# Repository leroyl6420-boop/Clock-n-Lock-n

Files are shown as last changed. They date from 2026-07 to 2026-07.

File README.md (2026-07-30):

# Clock'n Lock'n
A punch clock that you can use to keep track of the time you work and keep you motivated!

I worked on this project to get myself to do more work! I guess that you gotta work to get work done ;)

Pros:

- Gives you a physical item as proof of your work!
- Motivates you to get your things done!
- Fun to make!

Cons:

- I KEEP ON WORKING IN TEN HOUR CHUNKS AND I CANT STOP PLEASE HELP ME

I hope that my repo helps you make your very own Clock'n Lock'n! Have fun! (P.S. I used OLEDs which is why the screen in the picture below is glitched out)

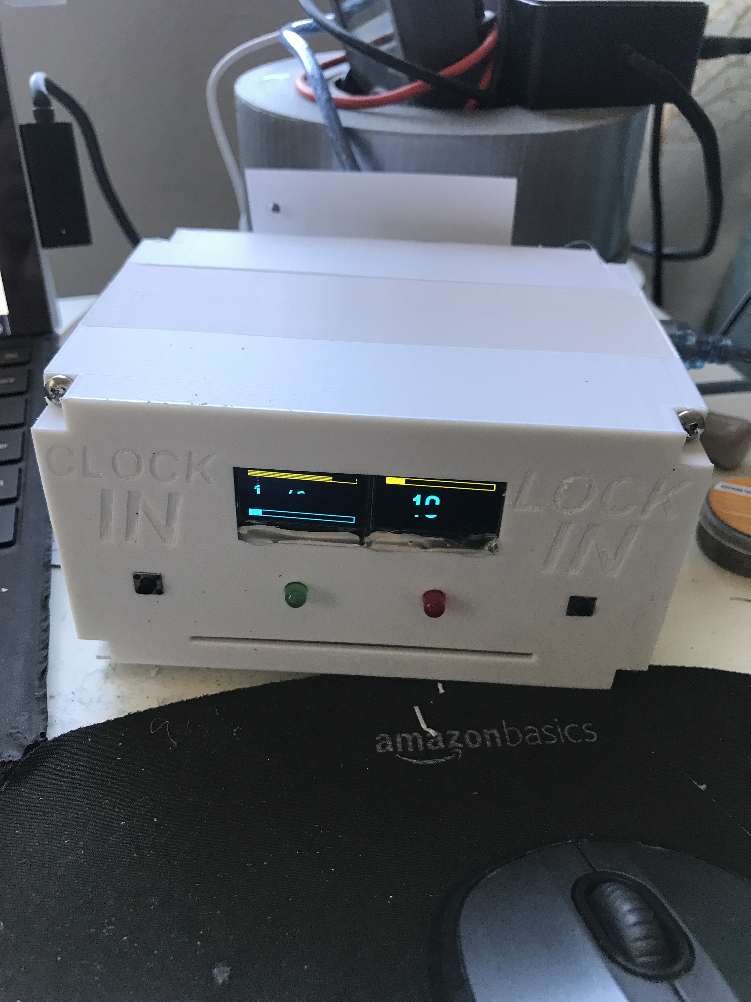
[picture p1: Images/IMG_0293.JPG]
An image of the finished Clock'n Lock'n!


The following are instructions on how to build the Clock'n Lock'n for yourself:

# PARTS TO PRINT

Print all of the parts in the Parts to Print file!

- Case
- Back Case
- Face
- Spiral Gear
- Servo Gear
- Pin

The total cost will vary based on what type of filament you use, and how many times you mess up the prints :P

# PHYSICAL COMPONENTS

Here is everything you need to buy off Amazon, AliExpress, and Temu: 

- 2 5mm LEDs: $0.04
- 2 5mm Push Buttons: $0.50
- 2 128x64 OLEDS: $5.00
- 1 28BYJ-48 Stepper Motor plus ULN2003 Motor Driver: $5.00
- 1 SG90 Servo Motor: $1.20
- 1 Mini Breadboard: $1.25
- 1 Arduino Uno R3: $8.00
- 4 220 ohm Resistors: $0.20
- 2 1K ohm Resistors: $0.10
- 2 Photoresistors: $1
- 10 #6-32 1in Screws: $1.57
- Jumper Wires: Will Vary

In total, everything will run you around $23.86, definitely less than $30 (: 

# ASSEMBLY INSTRUCTIONS

Hot-glue the Arduino and the ULN2003 onto the back of the case. Hot glue the Servo motor onto its mount. Screw the 28BYJ-48 Stepper Motor onto its mount using two #6-32 screws. Attach the Servo Gear onto the Servo motor. Attach the Spiral Gear onto the Stepper motor. Put the pin in its slot with a pen's spring pushing it up. Hot glue all the LEDs, buttons, OLEDs, and photoresistors into place. Connect one leg of every LED and photoresistor to GND. Every LED's other leg goes to a 220 ohm resistor, then their digital pin (see in code). The photoresistors go to a 10k ohm resistor, then their analog pin (see code). Wire everything else as stated in code. Congrats, you have just built your very own Clock'n Lock'n!

# AI USE
AI was used to debug the code.

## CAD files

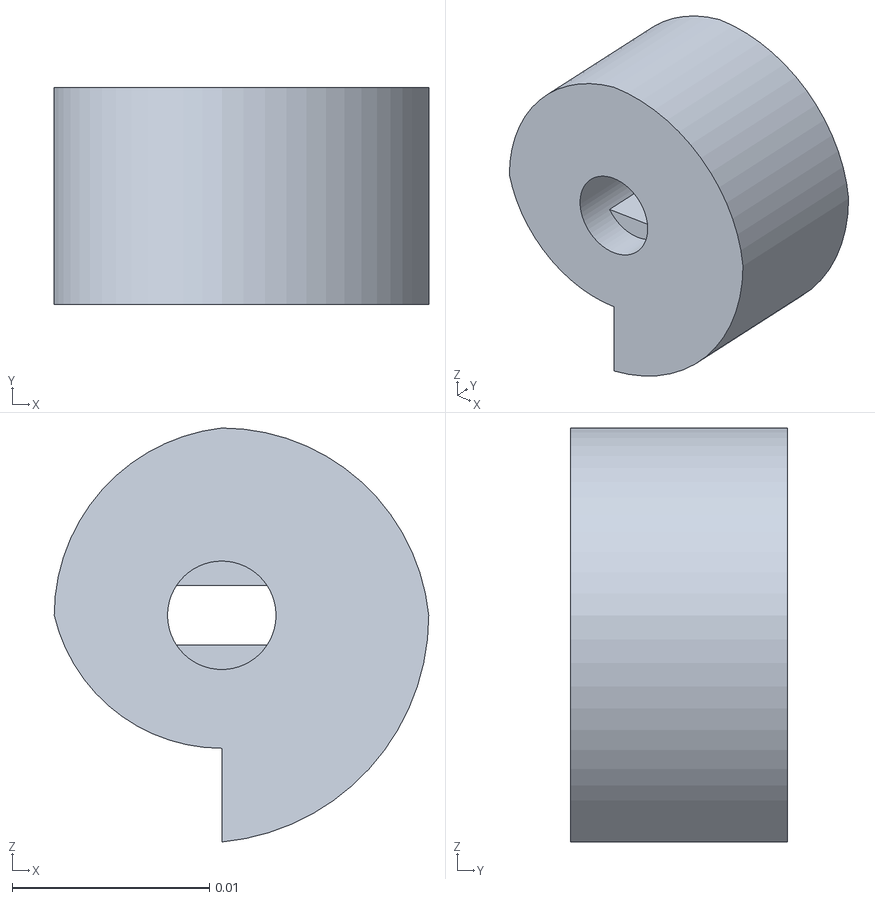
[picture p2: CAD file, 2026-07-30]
Parts to Print/Spiral Gear.stl
0.019 x 0.011 x 0.021

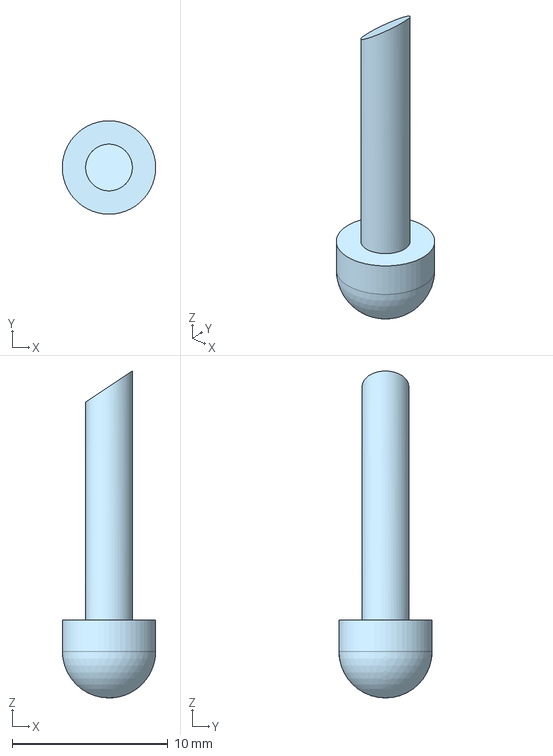
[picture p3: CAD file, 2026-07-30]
STEP Files/Pin.step
6.00 x 6.00 x 21.0 mm

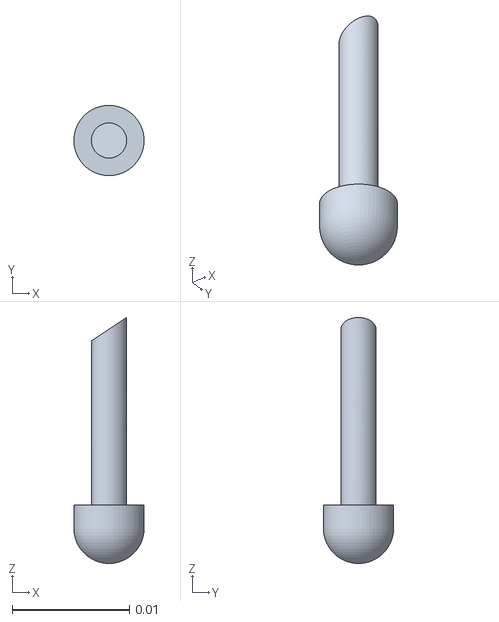
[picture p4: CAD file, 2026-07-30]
Parts to Print/Pin.stl
0.006 x 0.00599 x 0.021

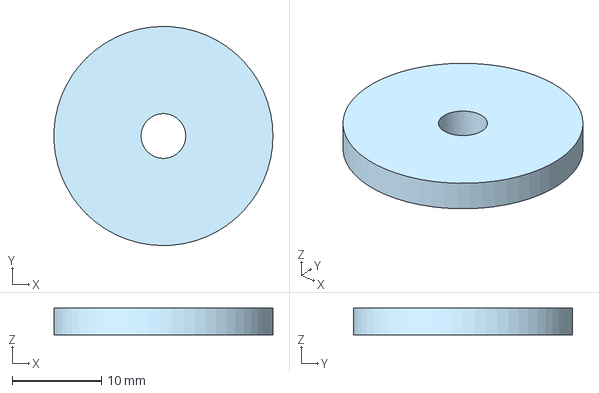
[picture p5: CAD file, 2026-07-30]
STEP Files/Servo Gear.step
24.5 x 24.5 x 3.00 mm

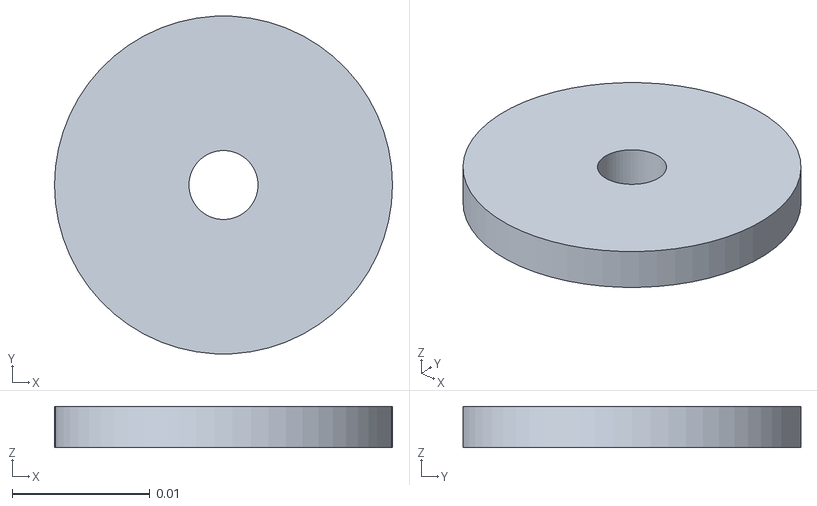
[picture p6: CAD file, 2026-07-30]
Parts to Print/Servo Gear.stl
0.0245 x 0.0245 x 0.003

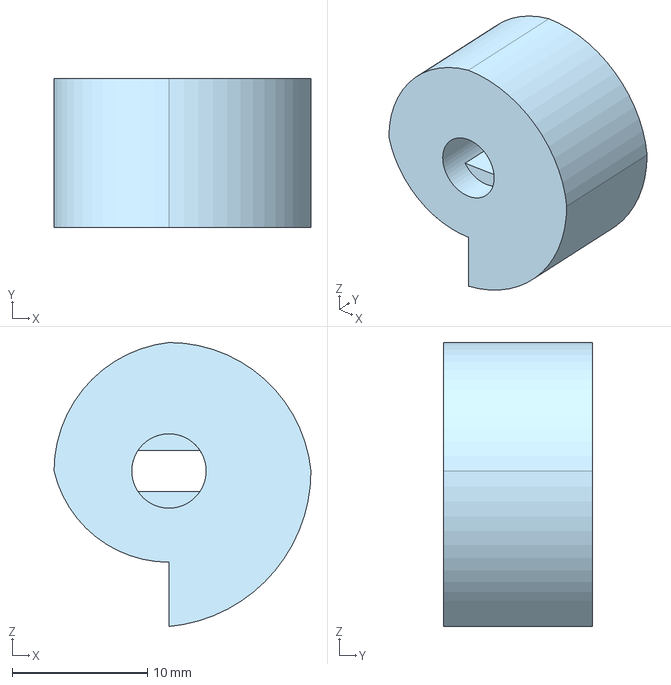
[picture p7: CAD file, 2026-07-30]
STEP Files/Spiral Gear.step
19.0 x 11.0 x 21.0 mm

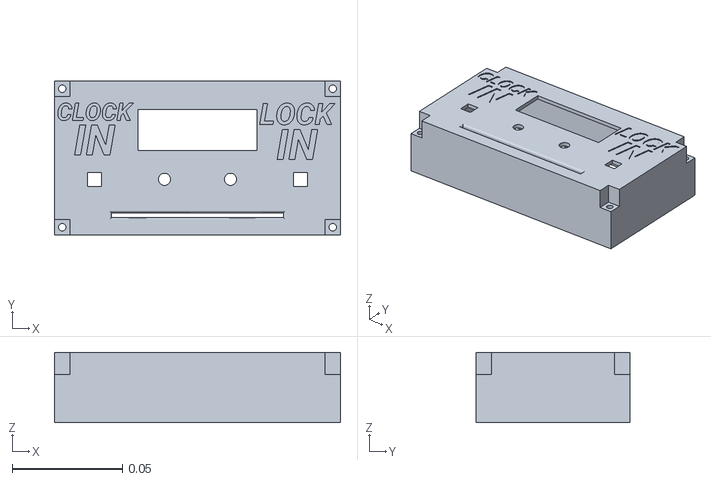
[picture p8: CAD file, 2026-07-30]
Parts to Print/Face.stl
0.13 x 0.07 x 0.032

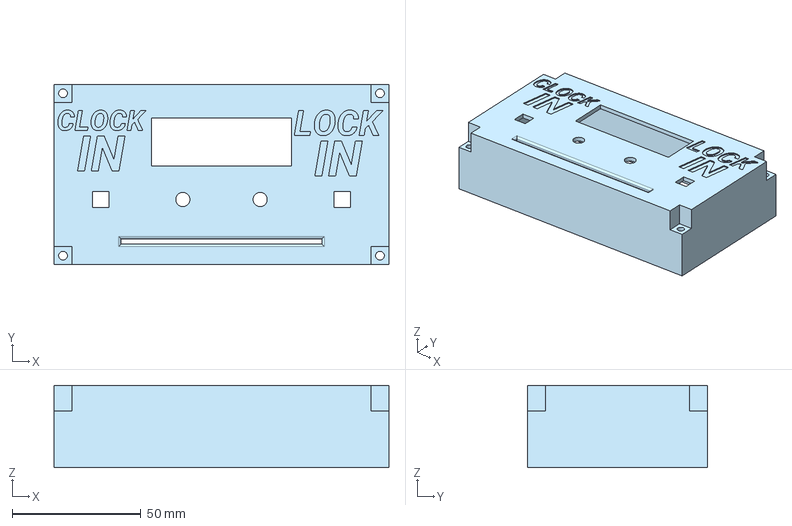
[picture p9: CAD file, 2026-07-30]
STEP Files/Face.step
130.0 x 70.0 x 32.0 mm

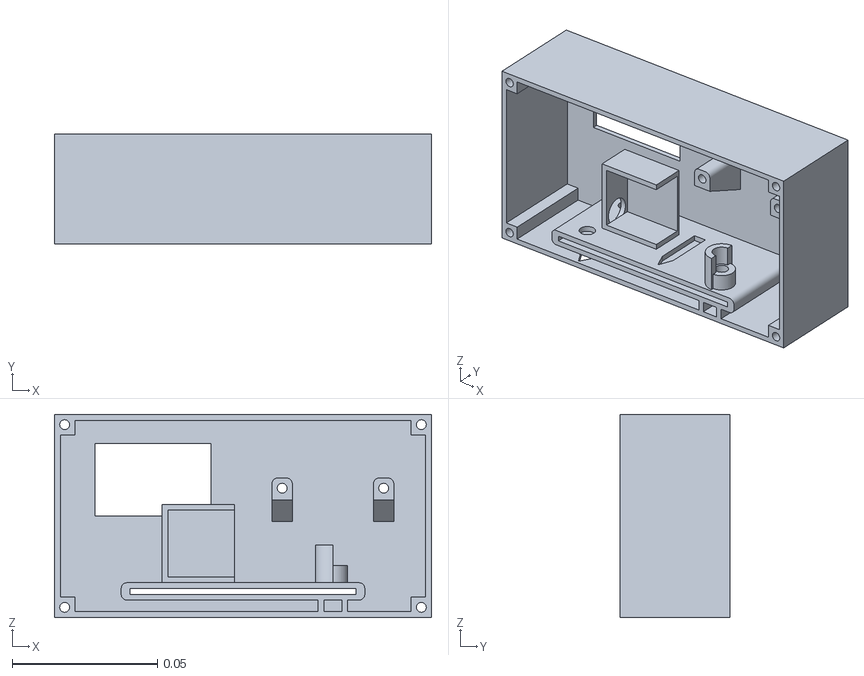
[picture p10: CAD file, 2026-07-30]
Parts to Print/Case.stl
0.13 x 0.038 x 0.07

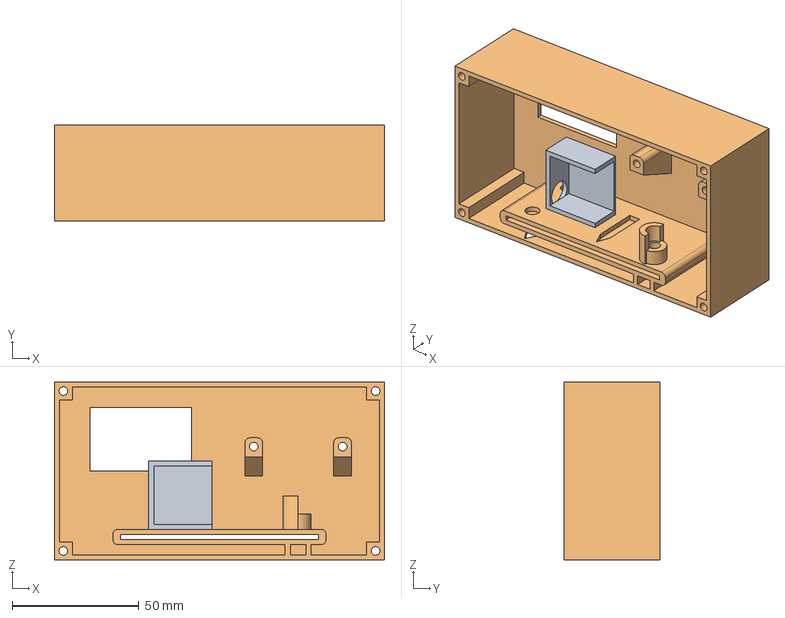
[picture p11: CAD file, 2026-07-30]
STEP Files/Case.step
130.0 x 38.0 x 70.0 mm

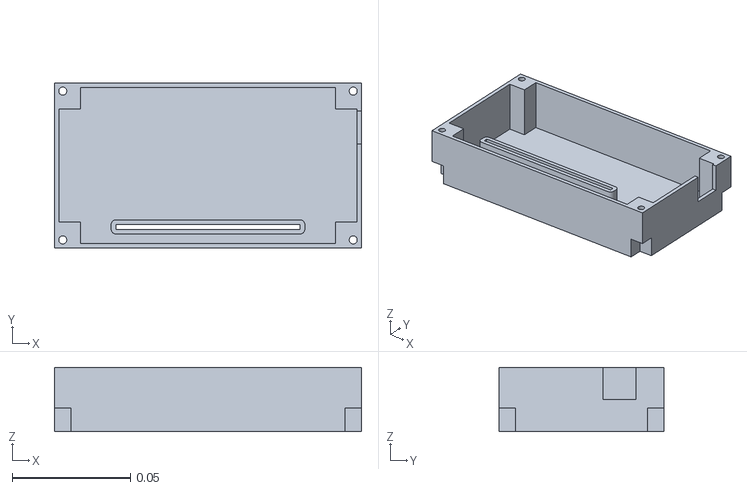
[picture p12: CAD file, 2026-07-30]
Parts to Print/Back Case.stl
0.13 x 0.07 x 0.0272

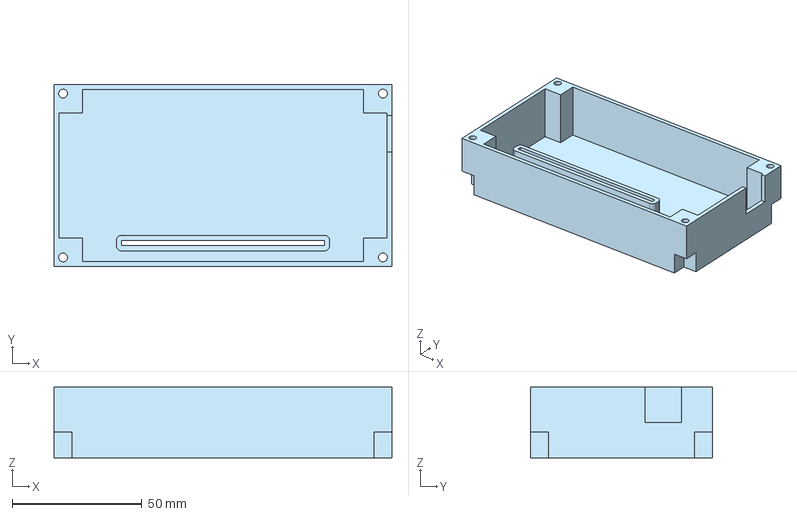
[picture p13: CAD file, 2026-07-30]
STEP Files/Back Case.step
130.0 x 70.0 x 27.2 mm

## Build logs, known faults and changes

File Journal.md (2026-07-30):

# Lock'n Clock'n

Hi! Welcome to my journal for my Lock'n Clock'n project!

# Devlog 1
1h 5m 4s Logged

I started the Lock'n Clock'n today! I cadded the case, the face, and the punch card. I think I'll just use index cards for those. I still don't know how I'll punch the cards, but I'm sure that I'll figure it out. In the meantime, I also added some 3D models of the parts I'll be using, and I CADed screw holes and text. I'm excited to keep going!

A picture of the initial Lock'n Clock'n CAD!

# Devlog 2
1h 21min Logged

I CADed the system that will detect the position of the punch card in the Clock'n Lock'n. There will be an LED and a photoresistor, and the LED will constantly shine on the photoresistor. However, when the punch card is pushed through, the photoresistor will sense the light level drop. When a hole on the side of the punch card comes up, the light level will return to normal, and the Clock'n Lock'n will know the position of the punch card. I also started CADing the movement system. I plan to use a 28BYJ-48 Stepper Motor for percise control. I will need a second LED-photoresistor system to trigger it, or I will need to move the initial one up. We'll see which is more convenient for spacing. Yes, space management has been a real issue in this project. I wanted it to take up little space, so you could easily put it on your desk, but it seems I will have to make some comprimises. 

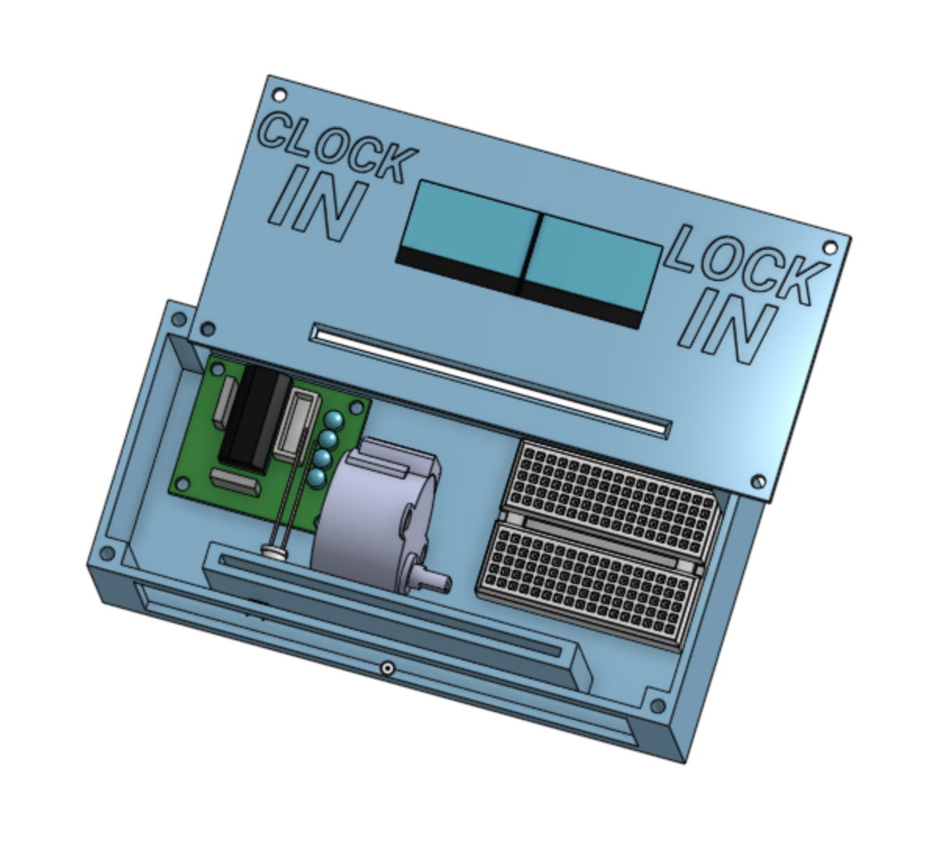
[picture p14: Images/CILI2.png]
An image of the Clock'n Lock'n with its partially completed position-detecting and punch-card-moving systems


# Devlog 3
1h Logged

I CADed the Stepper mount and the wheel that will push the paper through the slot. Not a lot to say, just took a long time. 

Exactly what it sounds like

# Devlog 4
1h 41min 28sec Logged

I coded and built the first prototype of the Clock'n Lock'n! I just had one position detection module and the movement module for now. The code was pretty simple, just a continuously spinning motor and a reading photoresistor. I think that I need a two-point axle for the movement module, as it was too flimsy and wouldn't hold in place. The position detection system worked well, as it gave a 32-unit difference between the punches. I need to make the case larger to fit an internal puncher and the movement module's second axle point. In the meantime, the test worked well!

An image of the first test of the Clock'n Lock'n

# Devlog 5
1h 20min Logged

I got rid of the 28BYJ-48 Stepper motor and replaced it with a modified SG90 servo motor. I modified it by disconnecting the encoder and getting rid of the mechanical plastic catch, making it bacically a mini high-torque dc motor. I can control the speed, but I can't control the position anymore (due to the disconnected encoder). That's alright, as I can tell the position of the punch card anyway through the LED-photoresistor modules. Getting rid of the 28BYJ-48 in favor of the SG90 also has the benefit of saving space in the case, not only with the motor itself but also in the lack of a driver module. 

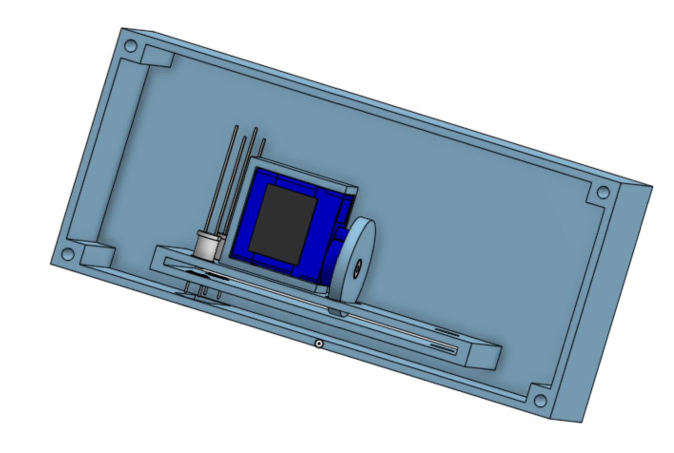
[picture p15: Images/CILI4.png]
A picture of the Clock'n Lock'n CAD, now with a servo motor instead of a stepper motor


# Devlog 6
1h 10m 50sec Logged

I coded the test code and part of the actual code. I had to spend time coding the logic on the positioning, and I also had to do some soldering on the back of one of my OLEDs to change its adress. Again, not a lot to say, just a lot of difficult work, troubleshooting, but getting there in the end (:

An image of the OLED which had its adress changed

# Devlog 7

42 min Logged

I built the first prototype of the Clock'n Lock'n! I couldn't figure out the stamping mechanism just yet, so I had to use a makeshift puncher consisting of a sharp chopstick, a bottle cap, and two pen springs. The new servo moving system works very well, though the position detection systems are not yet online. I need to make a hole puncher first. Overall, the tests that I set out to do with this prototype were all successes! I have new ideas on how to implement a stamp, like a solenoid (with a relay). 

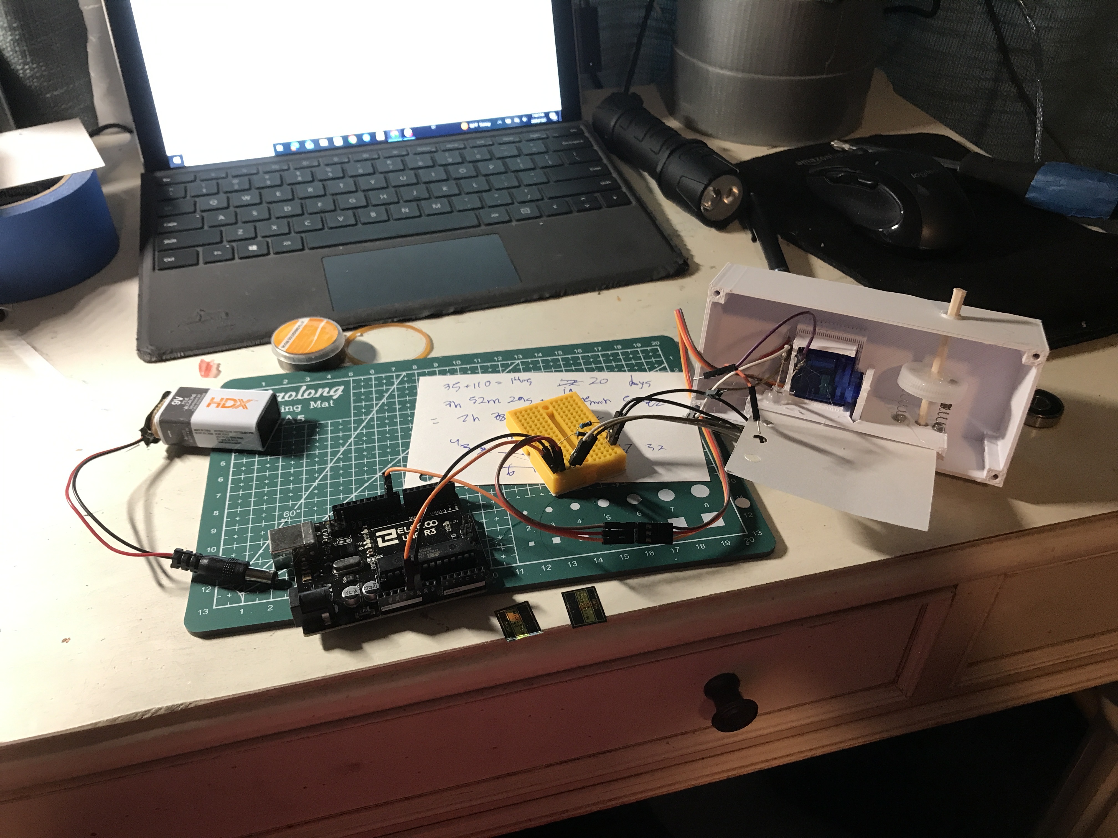
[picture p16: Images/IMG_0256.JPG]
A picture of the first prototype of the Clock'n Lock'n!


# Devlog 8
1h 32min Logged

I CADed a system to automatically punch holes in the paper! I did a lot of brainstorming, and I landed on a small pin with a rounded head that a cam would push onto. I modeled the bulk of it already, but I need to do some real-world testing before making any more decisions. I'm using a spring to hold the pin up, which is hard to model around. I also had to move the roof higher to fit the 28BYJ-48 stepper motor that I'm adding back, which sucks because I want to make this device as small as possible. Still, I'm telling myself that it was necessary, because the roof is now full of stuff and I can't put the buttons/LEDs that I was planning to add there. Instead, I'll have to add them onto the elongated face. 

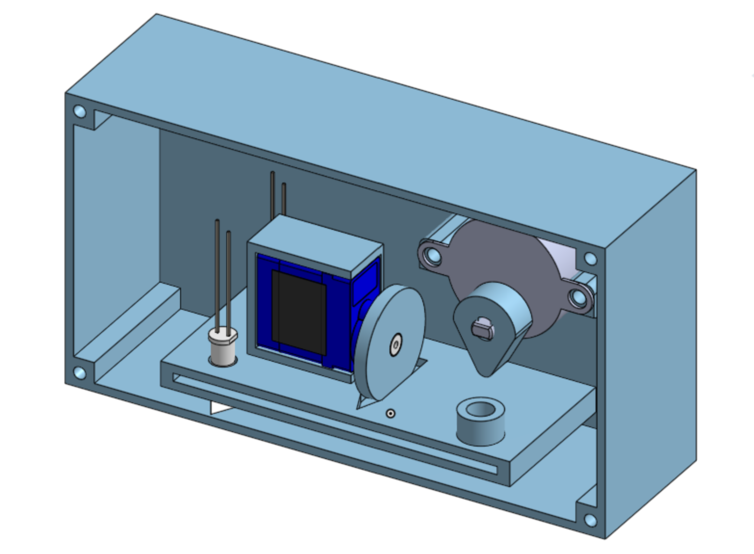
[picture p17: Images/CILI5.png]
An Image of the Clock'n Lock'n with the punch system modeled


# Devlog 9
1h Logged

I CADed a test case (without walls) to test the punch system while saving time and filament. I also CADed the puncher that I'll use to punch the 10 pre-punched holes into the index card. A lot of work, not a lot of words. 

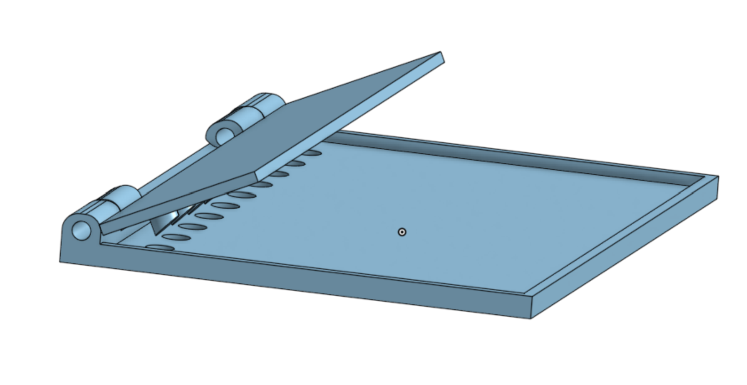
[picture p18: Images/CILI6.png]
An image of the index card puncher

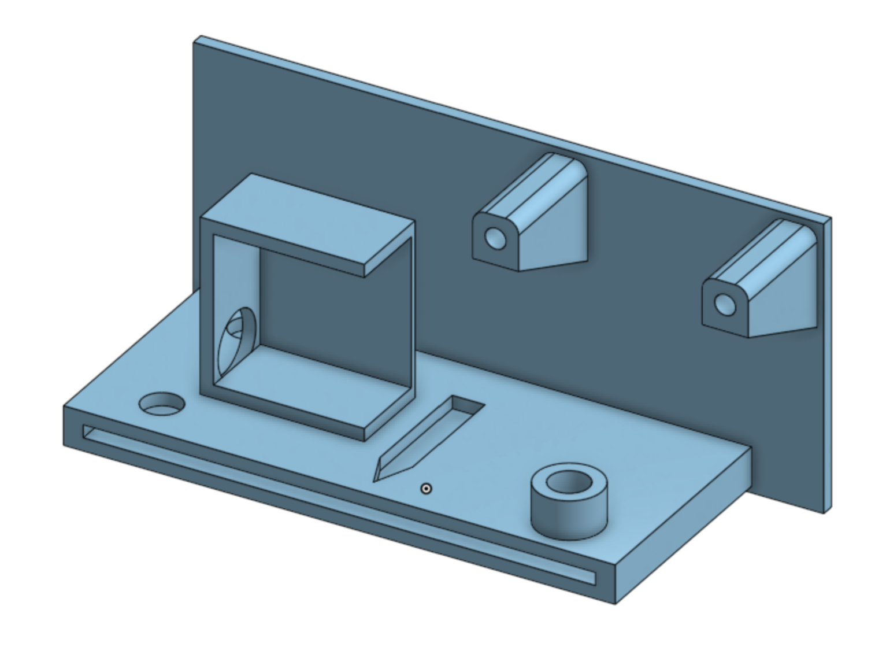
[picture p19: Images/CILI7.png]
An image of the test case


# Devlog 10
2h 17min Logged

Long working session! Lost track of time, I would have made seperate devlogs, but I'll just split this one into a software section and a hardware section. The software section goes first!

I coded the OLEDS into the Main file, and I coded the 28BYJ-48 Stepper Motor into both the Main file and the Test file. I coded some more logic into the Main file as well, like the paper positioning, the hole punching due to the hour count, etc. I was informed that each OLED screen will need 1024 bytes of RAM, but the Arduino Uno R3 only has 2000 available for the both of them. This means that I will need to work with a library that will lower the RAM usage in exchange for slower rendering times. I'm not worried about this, as the OLEDs' main function will be a clock and a progress bar. 

I printed out the testing case and attached the stepper motor with its cam gear. It seems that, while all dimensions are perfect in my model, the same can't be said in real life. Thankfully, I have prepared for this. I can fix the dimensioning problem by simply elongating the pin's length. However, I do need to fix the issue of the cam pushing the pin to its side instead of down. I will do this by modeling a wall for the pin to slide against. 

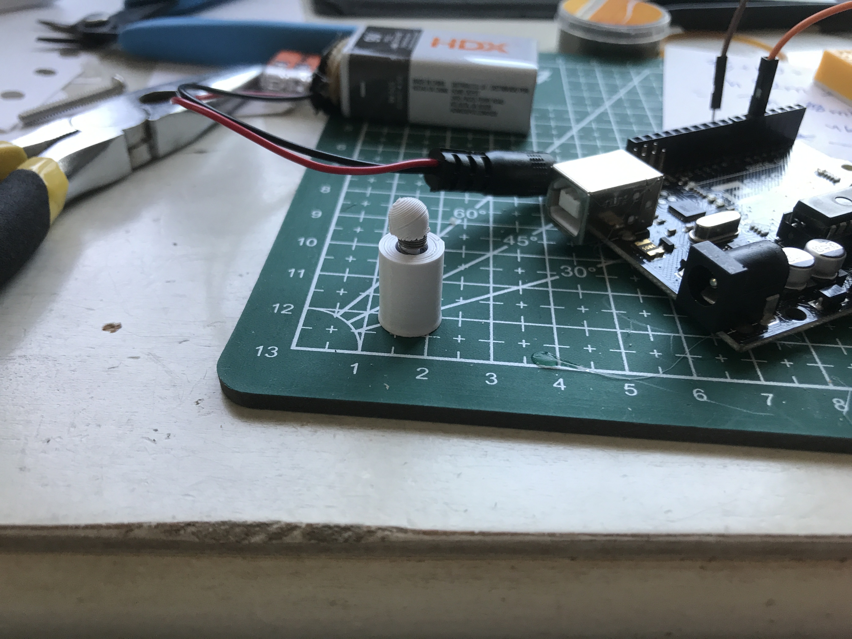
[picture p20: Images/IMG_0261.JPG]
An image of the hole-punching mechanism's testing model

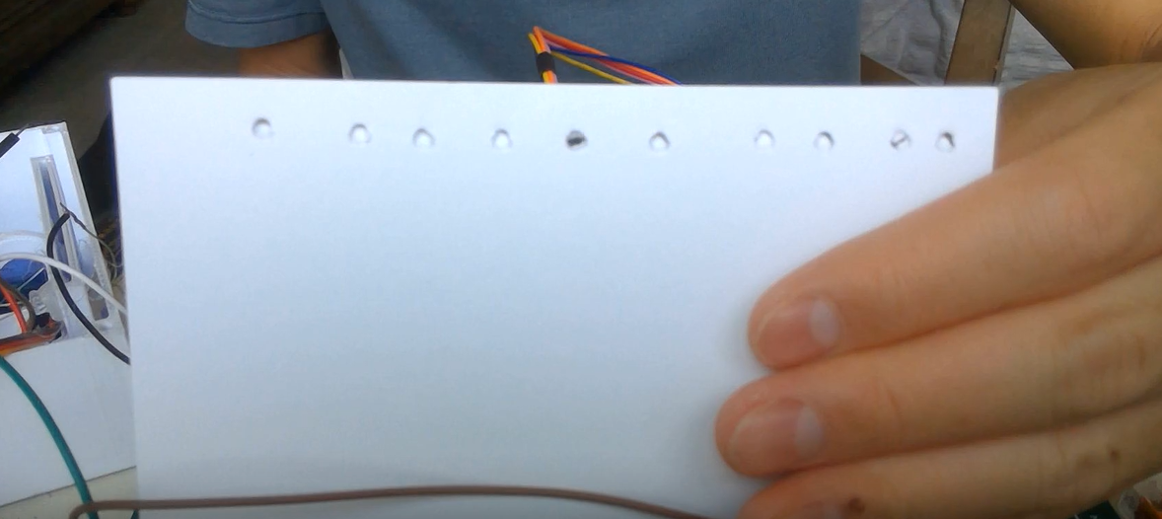
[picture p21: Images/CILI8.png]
An image of the holes the hole-punching mechanism made in the paper

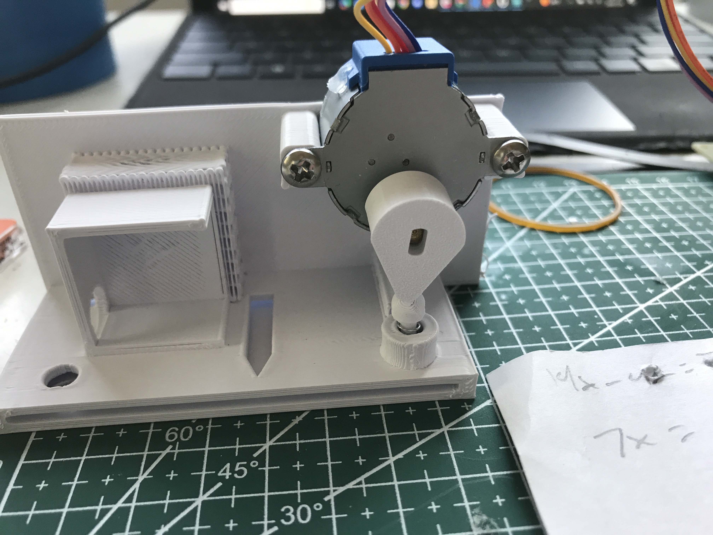
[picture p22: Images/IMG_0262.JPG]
An image of the test case with the stepper motor, its cam gear, the pin, and the pin's spring


# Devlog 11
2h 3min Logged

Another long stretch of work! I may not need a Clock'n Lock'n after all ;) I mostly finished the cam system, added the final touches to the case's CAD, worked on the puncher, and did more coding in the Main file. I need to figure out a way to make a progress bar! It's my first time working with two OLED screens. 

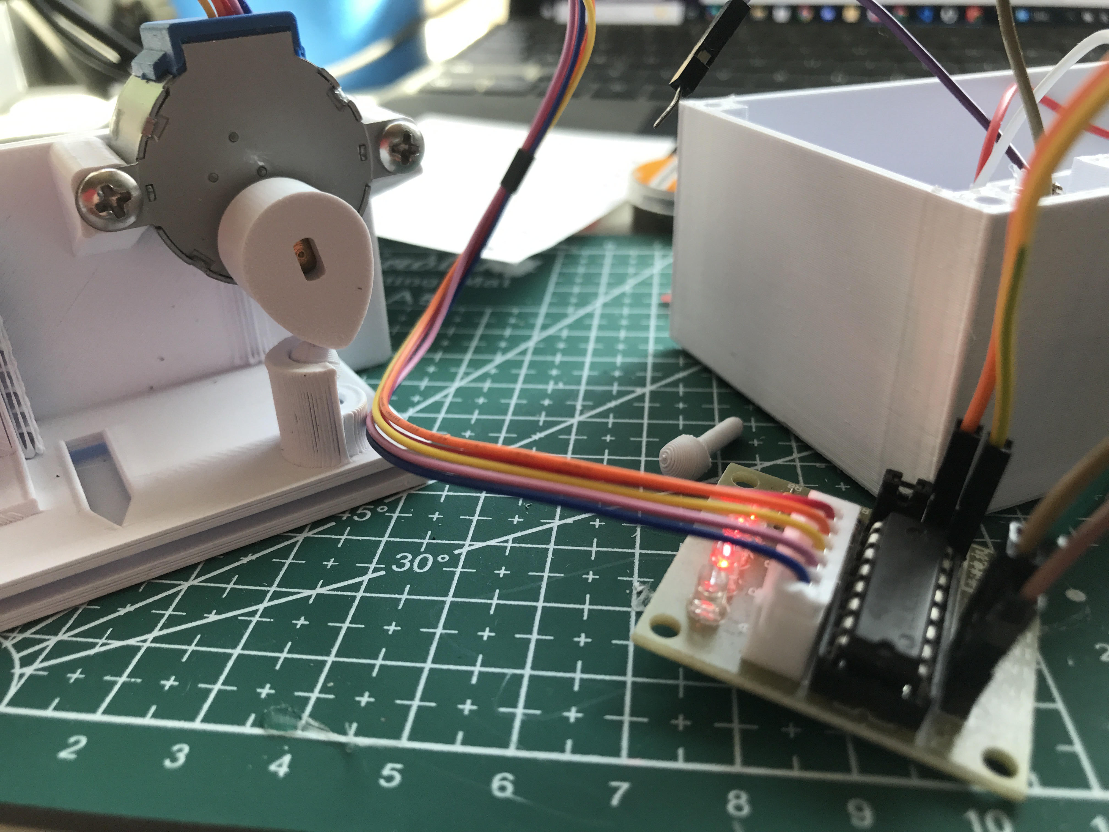
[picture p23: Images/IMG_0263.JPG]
An image of the updated hole-punching mechanism


# Devlog 12

2h Logged

I diagnosed the puncher's issue as the cam gear pushing the pin down too fast. To slow the process down, I replaced the cam gear with a spiral gear. It distributes the 4mm push across the entire circumference. I also added supports beneath the paper chute to hold it up while the pusher pushes down. Though the punched hole is smaller than I intended, I am just glad that it works. 

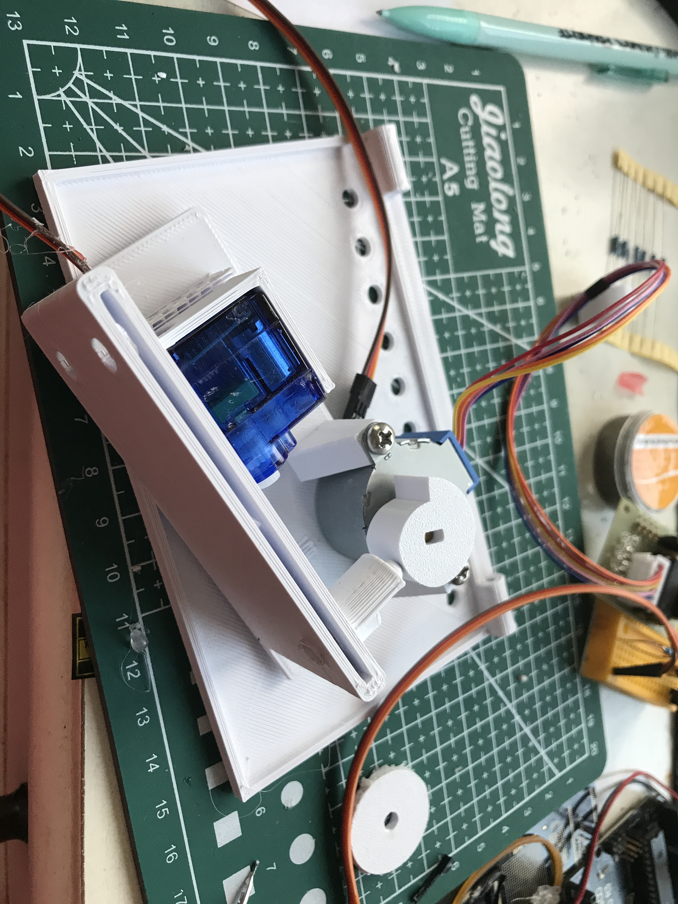
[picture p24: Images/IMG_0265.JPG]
An image of the test case with the spiral gear attached instead of the cam gear


# Devlog 13
1h 55min Logged

I finished coding the Clock'n Lock'n! Well, at least the first complete version of it. I'll probably be back fixing bugs before I know it. I added the screen displays, the punching system, the movement system, and the positioning logic. I'm currently printing out all the parts of the Clock'n Lock'n, I can't wait to try the code out!

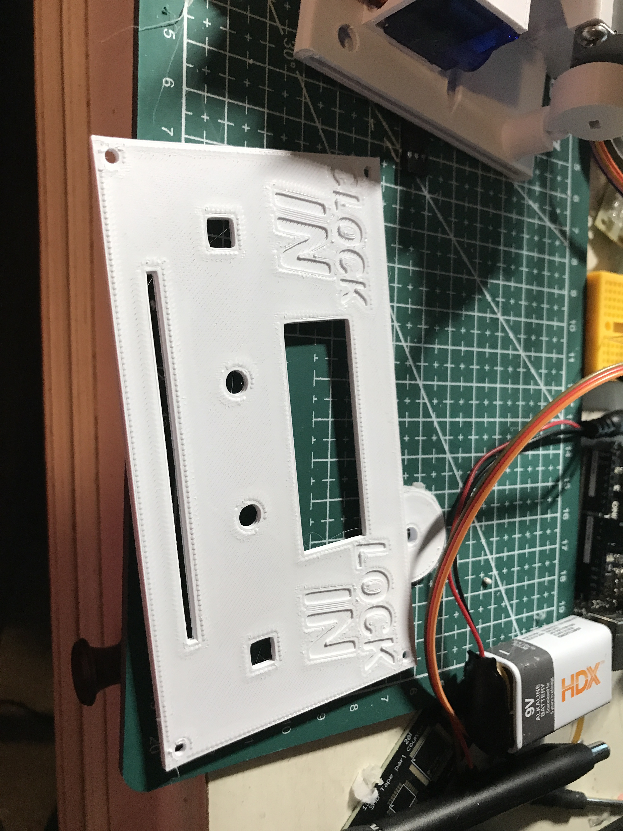
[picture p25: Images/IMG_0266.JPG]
An image of the printed Clock'n Lock'n face


# Devlog 14
1h 2min Logged

I built part of the final Clock'n Lock'n! I got the LEDs and photoresistors soldered and glued in, along with both the servo motor and the stepper motor. I think I may finish it tomorrow! Here's a picture of the work thus far:

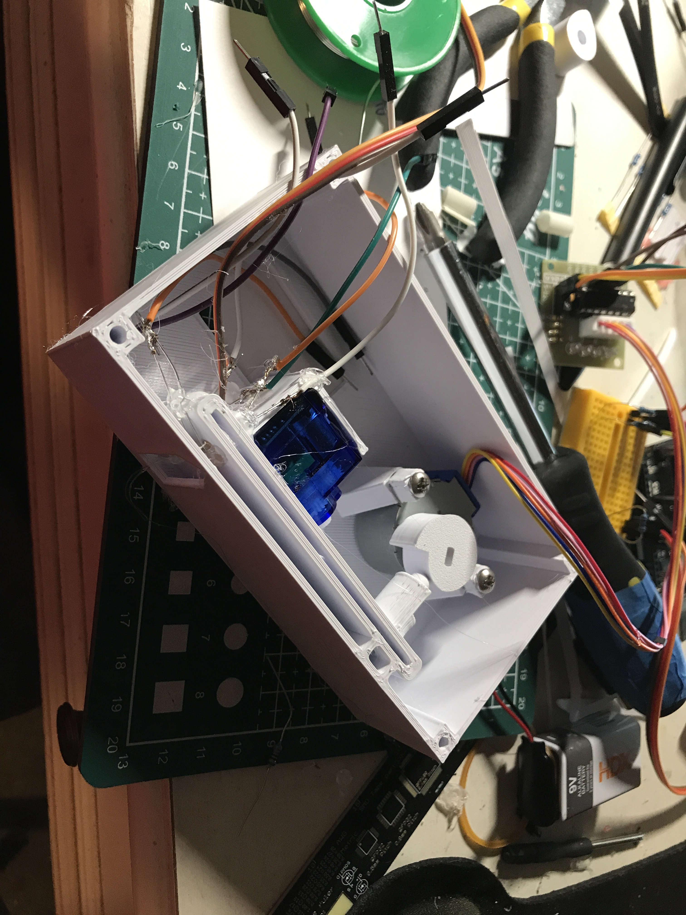
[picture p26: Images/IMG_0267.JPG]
Exactly what I said up there


# Devlog 15
1h 47min Logged

I built most of the Clock'n Lock'n! I had to solder wires to the two remaining LEDs and the two buttons, and I had to do a bunch of wiring for all the parts. I decided to put the breadboard in the main chamber and the Arduino Uno R3 with the ULN2003 into the back chamber. Things are really cramped and sometimes it's hard to get wires where they need to go, but I'm managing. I still need to wire the OLEDs and the LEDs and buttons on the face. 

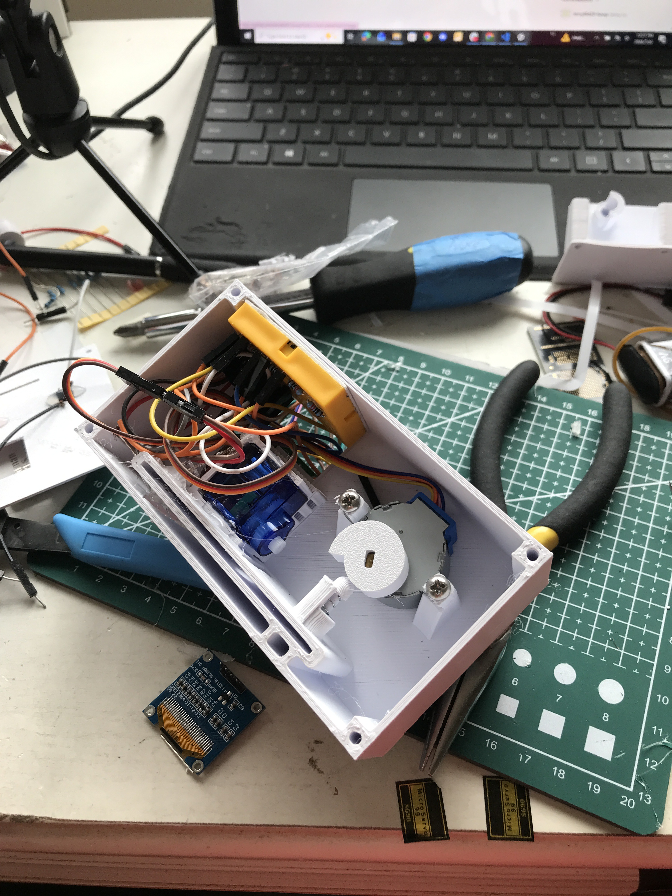
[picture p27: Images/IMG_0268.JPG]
A picture of the in-progress Lock'n Clock'n

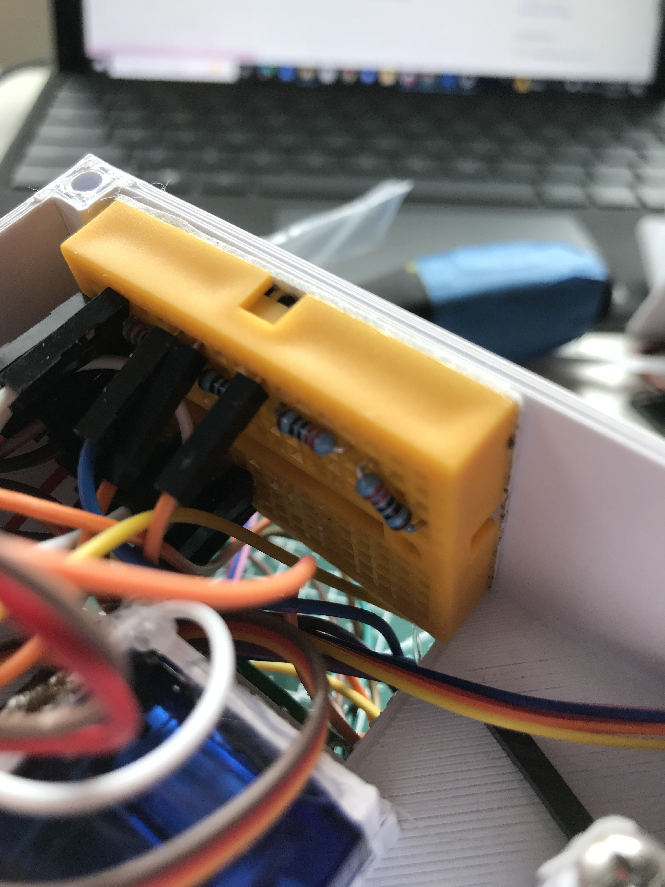
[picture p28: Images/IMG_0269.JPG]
A close-up picture of the breadboard

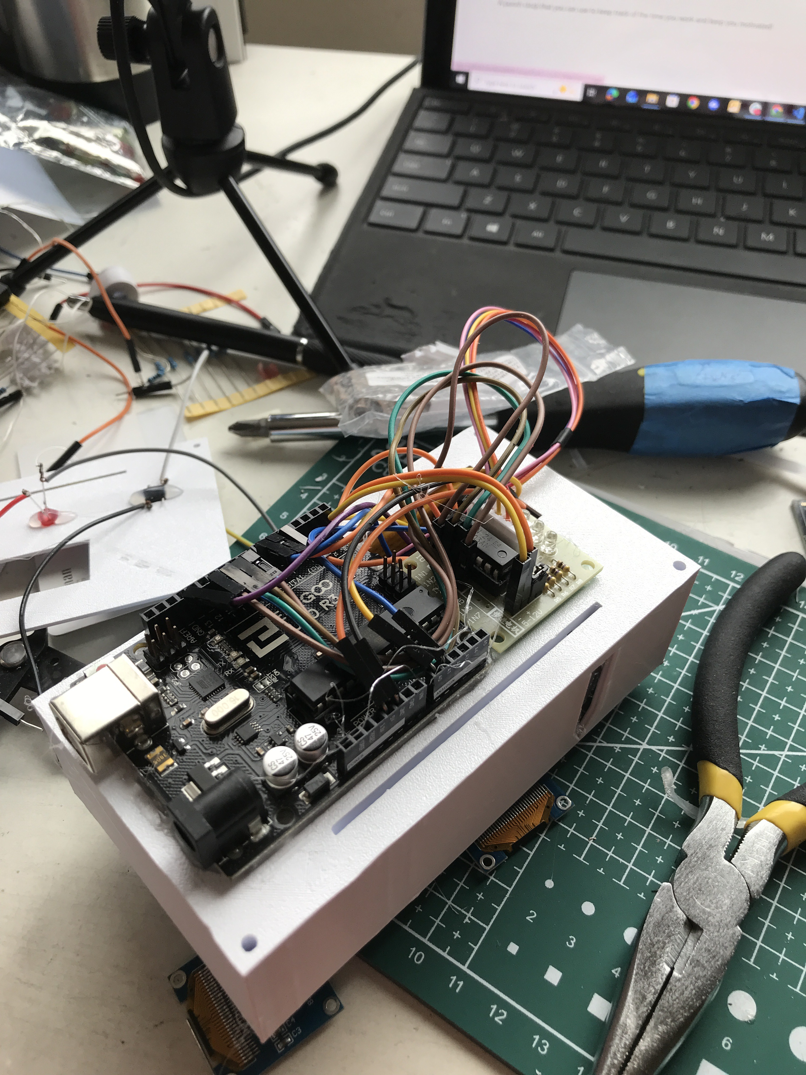
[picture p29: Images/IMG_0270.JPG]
A picture of the exposed back compartment, with the ULN2003 and the Arduino Uno R3


# Devlog 16
1h 26min Logged

I wired all of the components of the Clock'n Lock'n! It's almost fully built, even if I had to resolder some wires and reattach some jumpers. It's getting really sketchy, and when I tried putting the face on, it wouldn't fit! The same happened when I tried putting the back case on. To remedy this, I CADed a face and a back case which have taller walls. In the meantime, the Clock'n Lock'n is looking promising!

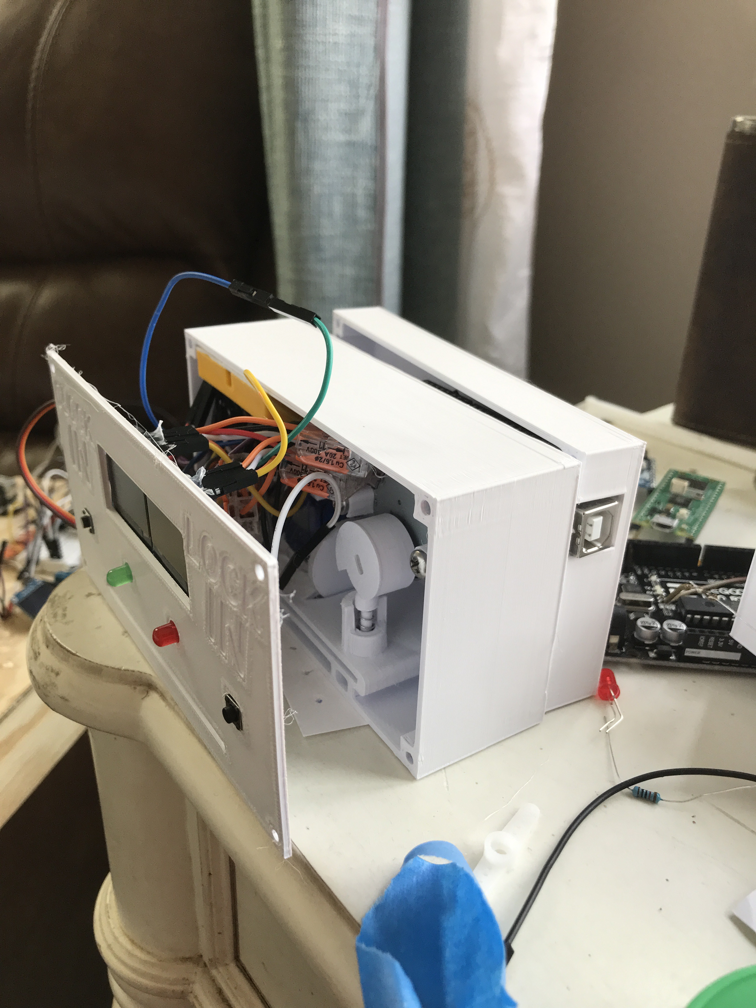
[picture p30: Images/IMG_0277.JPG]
A picture of the mostly-completed Clock'n Lock'n


# Devlog 17
1h 45min 10sec Logged

I debugged the code and added slots for the screws in the CAD models. Not a ton to say. Really took a long time, though. I guess this is a good sign that I'm getting to these things, I think it means I'm nearing completion (:

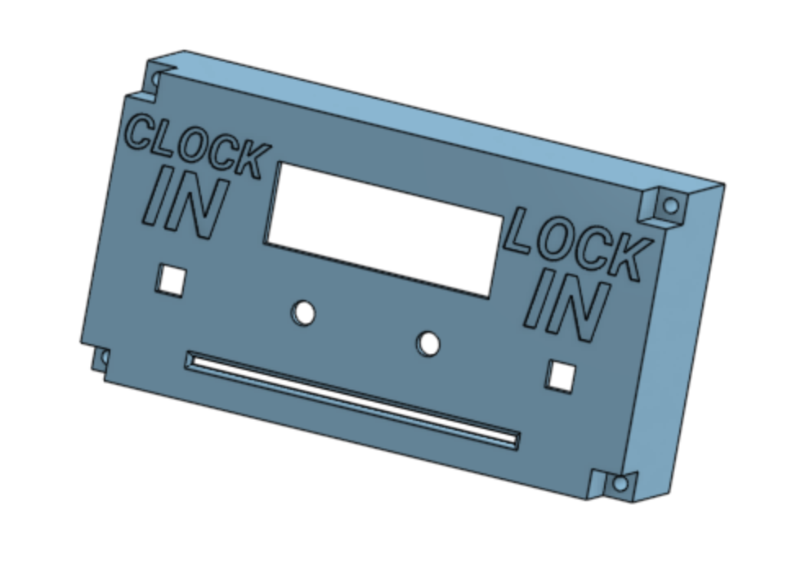
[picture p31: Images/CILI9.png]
The front face's CAD model with slots for the screws


# Devlog 18
1h 22min Logged

I finished the Clock'n Lock'n! I printed the updated face and back case, and everything fits! The time tracking works well, and the punching does too, even if it could be a little more accurate. It seems I'll have to give any machine that takes the completed index cards plenty of margin. I'll be shipping the project now! YAY!

The finished Clock'n Lock'n!

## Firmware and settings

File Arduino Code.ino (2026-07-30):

//Servo is modified! 163 keeps it still because my SG90 Servo was modified while the encoder was at 163 degrees. Yours might be different!
//You can adapt an SG90 Servo motor by taking out the screws on its base, then clipping the part of the shaft that is feeding into
//the encoder. It should have a D-shape. If that is too difficult, you can alternatively cut the wires connecting the encoder to the control
//module, though that should be avoided due to being a waste of a perfectly good encoder. If you would not like to deal with the hassle of 
//finding the position your encoder was in when you disconected it, you may set your encoder to a specific angle prior to disabling it. 
//However, this is also discouraged, as it will require you to disable the encoder by cutting its wires. Cutting the shaft will cause the 
//encoder to shift. Your SG90 may also have a little mechanical catch. You may get rid of it however you like. 
#include <Arduino.h>
#include <Wire.h>
#include <Adafruit_GFX.h>
#include <Adafruit_SSD1306.h>
#include <Servo.h>
#include <Stepper.h>
#include <U8g2lib.h>
#define WIDTH 128
#define HEIGHT 64
#define PR1 A0
#define PR2 A1
#define LED1 6
#define LED2 7
#define LED3 12
#define LED4 13
#define SERVO 5
#define OLED_RESET -1
#define IN1 8
#define IN2 9
#define IN3 10
#define IN4 11
const int stepsPerRevolution = 2048;
Stepper myStepper(stepsPerRevolution, 8, 10, 9, 11);
int position = 0;
int hours = 0;
int seconds = 0;
int minutes = 0;
int time = 0;
bool count = false;
int pm = 0;
int ph = 0;
int md = 0;
int hd = 0;
int x = 0;
int xh = 0;
#define B1 3
#define B2 4
Servo myServo;
Adafruit_SSD1306 display1(WIDTH, HEIGHT, &Wire, OLED_RESET);
Adafruit_SSD1306 display2(WIDTH, HEIGHT, &Wire, OLED_RESET);

void setup () {
    Serial.begin(9600);
    pinMode(PR1, INPUT);
    pinMode(PR2, INPUT);
    pinMode(LED1, OUTPUT);
    pinMode(LED2, OUTPUT);
    pinMode(B1, INPUT_PULLUP);
    pinMode(B2, INPUT_PULLUP);
    pinMode(LED3, OUTPUT);
    pinMode(LED4, OUTPUT);
    myServo.attach(SERVO);
    myStepper.setSpeed(5);
    if (!display1.begin(SSD1306_SWITCHCAPVCC, 0x3C)) {
        Serial.println(F("SSD1306 allocation failed for Display 1"));
        for(;;);
    }
    if (!display2.begin(SSD1306_SWITCHCAPVCC, 0x3D)) {
        Serial.println(F("SSD1306 allocation failed for Display 2"));
        for(;;);
    }
    myServo.write(163);
    display1.clearDisplay();
    display2.clearDisplay();
    display1.setTextColor(SSD1306_WHITE);
    display2.setTextColor(SSD1306_WHITE);
    display1.display();
    display2.display();
}    

void loop () {
    digitalWrite(LED3, LOW);
    digitalWrite(LED4, LOW);
    int P1 = analogRead(PR1);
    int P2 = analogRead(PR2);
    digitalWrite(LED1, HIGH);
    digitalWrite(LED2, HIGH);
    
    if (position == 0){
        if (P2 < 990){
            do {
                myServo.write(150);
                P1 = analogRead(PR1);
                P2 = analogRead(PR2);
            } while (!(P1 < 990 && P2 < 990));
            do {
                myServo.write(150);
                P1 = analogRead(PR1);
                P2 = analogRead(PR2);
            } while (!(P1 > 990 || P2 > 990));
        }
        myServo.write(163);
        position = 1;
    }
    
    if (position == 9){
        if (hours >= 1){
            myStepper.step(2480);
            do {
                myServo.write(150);
                P1 = analogRead(PR1);
                P2 = analogRead(PR2);
            } while (!(P1 < 990 && P2 > 990));
            do {
                myServo.write(150);
                P1 = analogRead(PR1);
                P2 = analogRead(PR2);
            } while (!(P1 > 990 && P2 > 990));
            position ++;
            hours = 0;
            myServo.write(163);
        }
    }
    if (position >= 10){
        if (hours >= 1){
            myStepper.step(2480);
            unsigned long startTime = millis();
            while (millis() - startTime < 1000) {
                myServo.write(150);
            }
            myServo.write(163);
            seconds = 0;
            minutes = 0;
            time = 0;
            hours = 0;
            count = false;
            position = 0;
        }
    }

    if (hours >= 1 && position > 0 && position < 9){
            myStepper.step(2048);
            do {
                myServo.write(150);
                P1 = analogRead(PR1);
                P2 = analogRead(PR2);
            } while (!(P1 < 990 && P2 < 990));
            do {
                myServo.write(150);
                P1 = analogRead(PR1);
                P2 = analogRead(PR2);
            } while (!(P1 > 990 || P2 > 990));
            position ++;
            hours = 0;
            myServo.write(163);
    }
    if (digitalRead(B1) == 0 && position > 0){
        count = true;
        digitalWrite(LED3, HIGH);
    }
    if (digitalRead(B2) == 0 && count == true){
        count = false;
        time = 0;
        seconds = 0;
        minutes = 0;
        hours = 0;
        digitalWrite(LED4, HIGH);
    }
    if (count == true){
        time++;
    }
    if (time >= 100){
        seconds++;
        time = 0;
    }
    if (seconds >= 60){
        minutes++;
        seconds = 0;
    }
    if (minutes >= 60){
        hours++;
        minutes = 0;
    }

    pm = minutes / 3;
    md = pm * 6;
    x = md - 6;
    if (position == 0){
        ph = 0;
    } else {
        ph = position - 1;
    }
    hd = ph * 12;
    xh = hd - 12;
    display1.clearDisplay();
    display2.clearDisplay();
    if (pm < 11){
        display1.setTextSize(1);
        display1.setCursor(x, 0);
        display1.print(F("O"));
        do {
            x = x - 1;
            display1.setCursor(x, 0);
            display1.print(F("O"));
        } while (!(x <= 0));
    } else {
        display1.setTextSize(1);
        display2.setTextSize(1);
        display2.setCursor(x - 60, 0);
        display2.print(F("O"));
        do {
            x = x - 1;
            display2.setCursor(x - 60, 0);
            display2.print(F("O"));
        } while (!(x - 60 <= 0));
        x = 58;
        do {
            x = x - 1;
            display1.setCursor(x, 0);
            display1.print(F("O"));
        } while (!(x <= 0));
    }
    if (ph < 6){
        display1.setTextSize(2);
        display1.setCursor(xh, 48);
        display1.print(F("O"));
        do {
            xh = xh - 1;
            display1.setCursor(xh, 48);
            display1.print(F("O"));
        } while (!(xh <= 0));
    } else {
        display1.setTextSize(2);
        display2.setTextSize(2);
        display2.setCursor(xh - 60, 48);
        display2.print(F("O"));
        do {
            xh = xh - 1;
            display2.setCursor(xh, 48);
            display2.print(F("O"));
        } while (!(xh <= 0));
        xh = 52;
        do {
            xh = xh - 1;
            display1.setCursor(xh, 48);
            display1.print(F("O"));
        } while (!(xh <= 0));
    }
    display1.setTextSize(4);
    display1.setCursor(2 , 12);
    display1.print(ph);
    display1.setTextSize(3);
    display1.setCursor(26, 16);
    display1.print(pm);
    display2.setTextSize(5);
    display2.setCursor(7 , 11);
    display2.print(seconds);

    display1.display();
    display2.display();

    delay(10);
}

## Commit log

2026-07-26 Update Journal with Clock'n Lock'n progress
    Added details about the progress on the Clock'n Lock'n project, including wiring and component placement.
2026-07-30 Create STL FILES HERE!
2026-07-30 Rename Back Case (2).stl to Back Case
2026-07-30 Rename Face (3).stl to Face
2026-07-30 Rename Print Case (1).stl to Case
2026-07-30 Rename Back Case to Back Case.stl
    [Back Case.stl]
2026-07-30 Rename Print Case.step to Case.step
    [Case.step]
2026-07-30 Initialize Arduino project with servo and stepper control
    This code initializes an Arduino project that controls a servo and a stepper motor while displaying information on two OLED screens. It includes setup for buttons, LEDs, and various variables for tim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
2026-07-30 Rename Pin (3).stl to Pin.stl
    [Pin.stl]
2026-07-30 Rename Spiral Gear (1).stl to Spiral Gear.stl
    [Spiral Gear.stl]
2026-07-30 Rename Adapted Gear parts (2).stl to Servo Gear.stl
    [Servo Gear.stl]
2026-07-30 Rename Adapted Gear parts.step to Servo Gear.step
    [Servo Gear.step]
